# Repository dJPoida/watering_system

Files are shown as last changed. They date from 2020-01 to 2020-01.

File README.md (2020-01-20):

# dJPoidas Watering System
dJPoida's automated garden watering system.

This is a simple project for activating a water pump that sits inside a small reservoir to regularly water my herbs because I'm a numpty and always seem to forget. Homemade pizza is much nicer with fresh Basil, Oregano and Chilli!

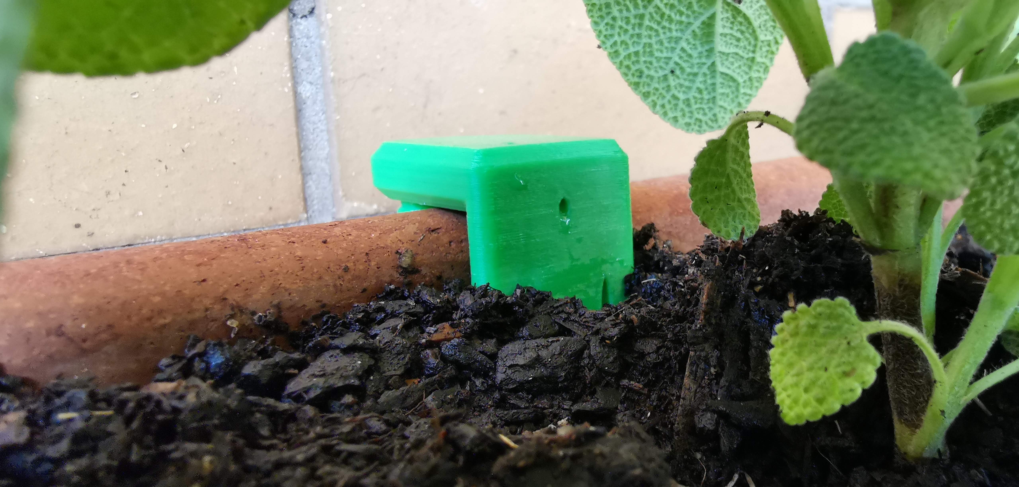
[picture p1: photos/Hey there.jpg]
Hey there

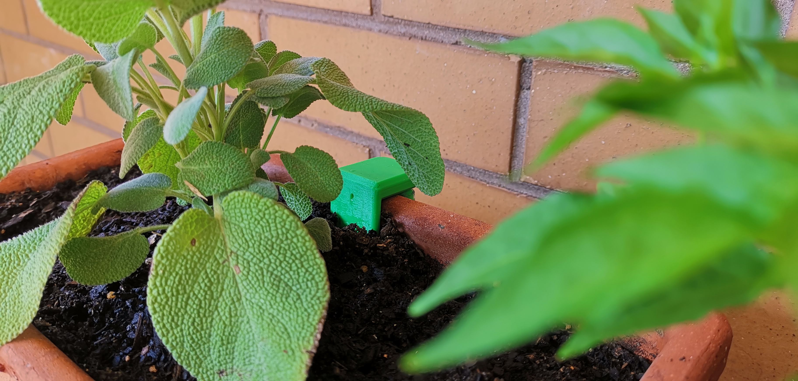
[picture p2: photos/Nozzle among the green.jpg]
Nozzle among the green

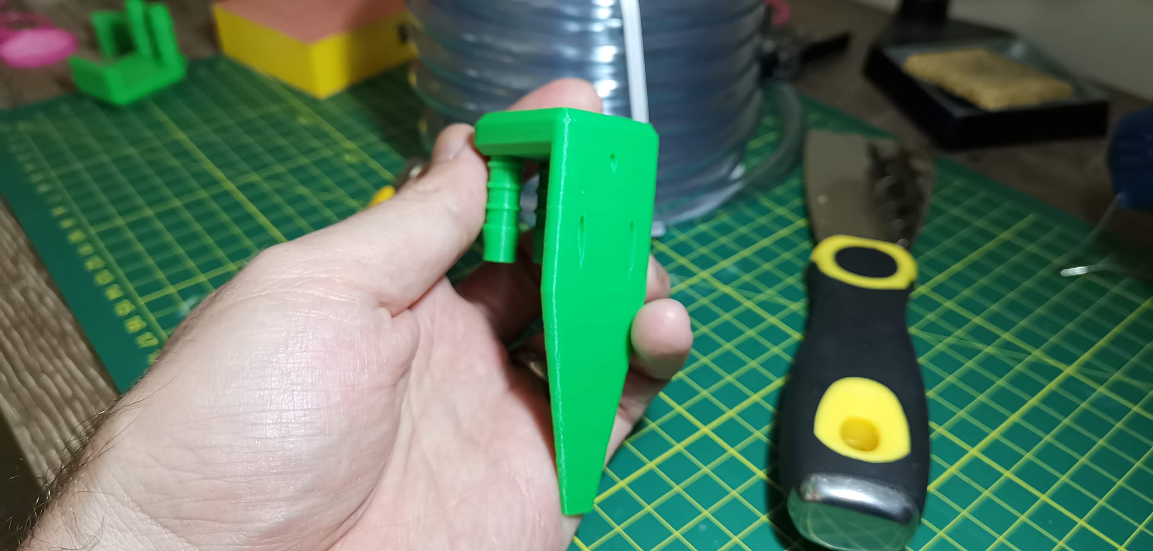
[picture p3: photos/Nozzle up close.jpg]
Nozzle up close

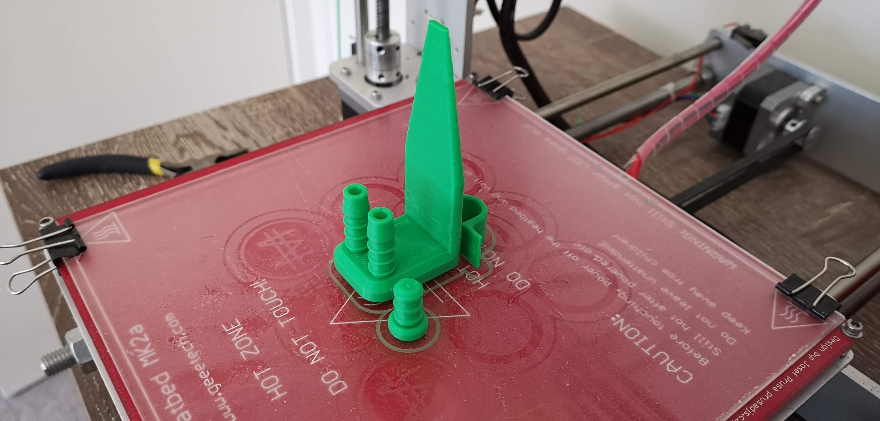
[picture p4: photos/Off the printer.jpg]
Off the printer

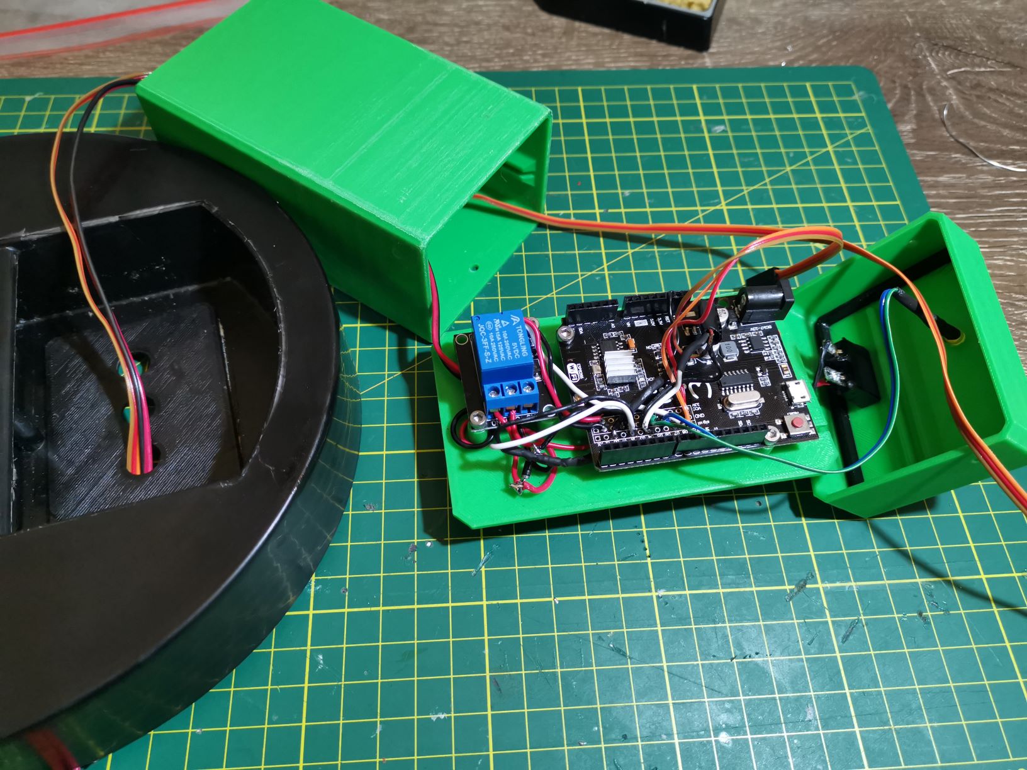
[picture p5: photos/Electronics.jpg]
Electronics

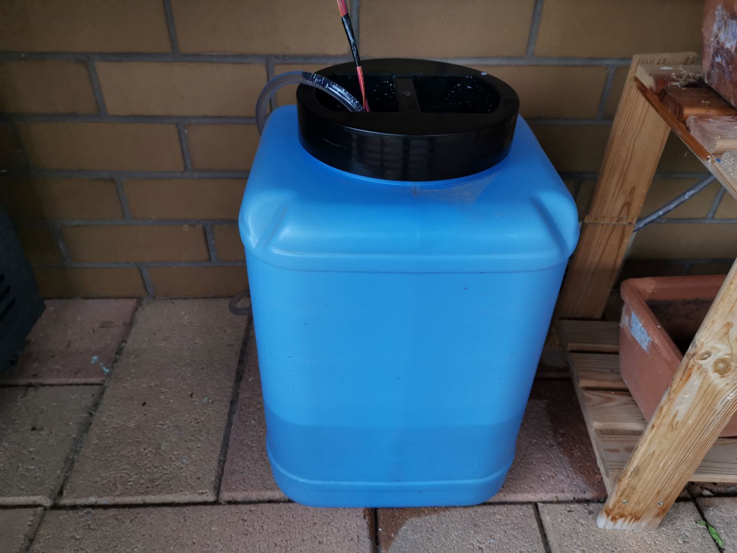
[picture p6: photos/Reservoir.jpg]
Reservoir

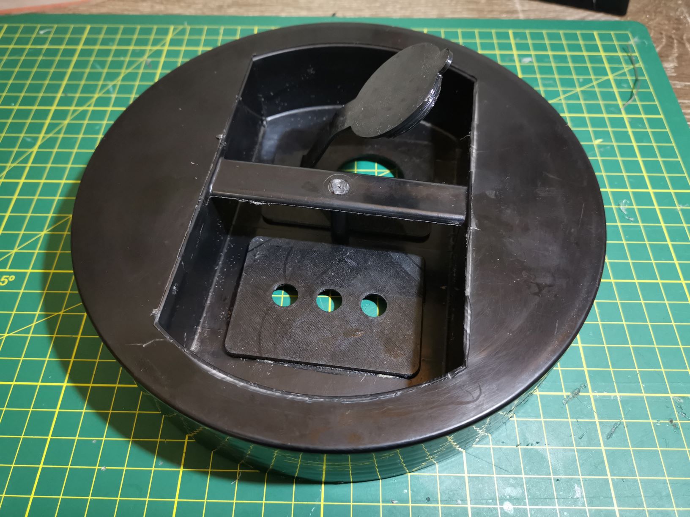
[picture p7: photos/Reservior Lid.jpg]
Reservior Lid


## Dependencies
### Arduino
The code for this project is written for the Arduino platform.
### Blynk
This project leverages the [Blynk IoT platform](https://blynk.io/) for remote management and reporting.

## Instructions
- Clone the repo
- Copy the `config_example.h` to `config.h` and populate with your appropriate config values. Specifically:
    - `blynkAuthToken[]`
    - `ssid[]`
    - `pass[]`
- Set your board config properly before uploading or the pins and flash won't work properly: 
    - LOLIN(WEMOS) D1 R2 & Mini
    - Flash Size: 4M (1M SPIFFS)
- Install Blynk on your control device (mobile / tablet) and load the control app by scanning the QR Code

## Blynk App
This is what the Blynk control app looks like
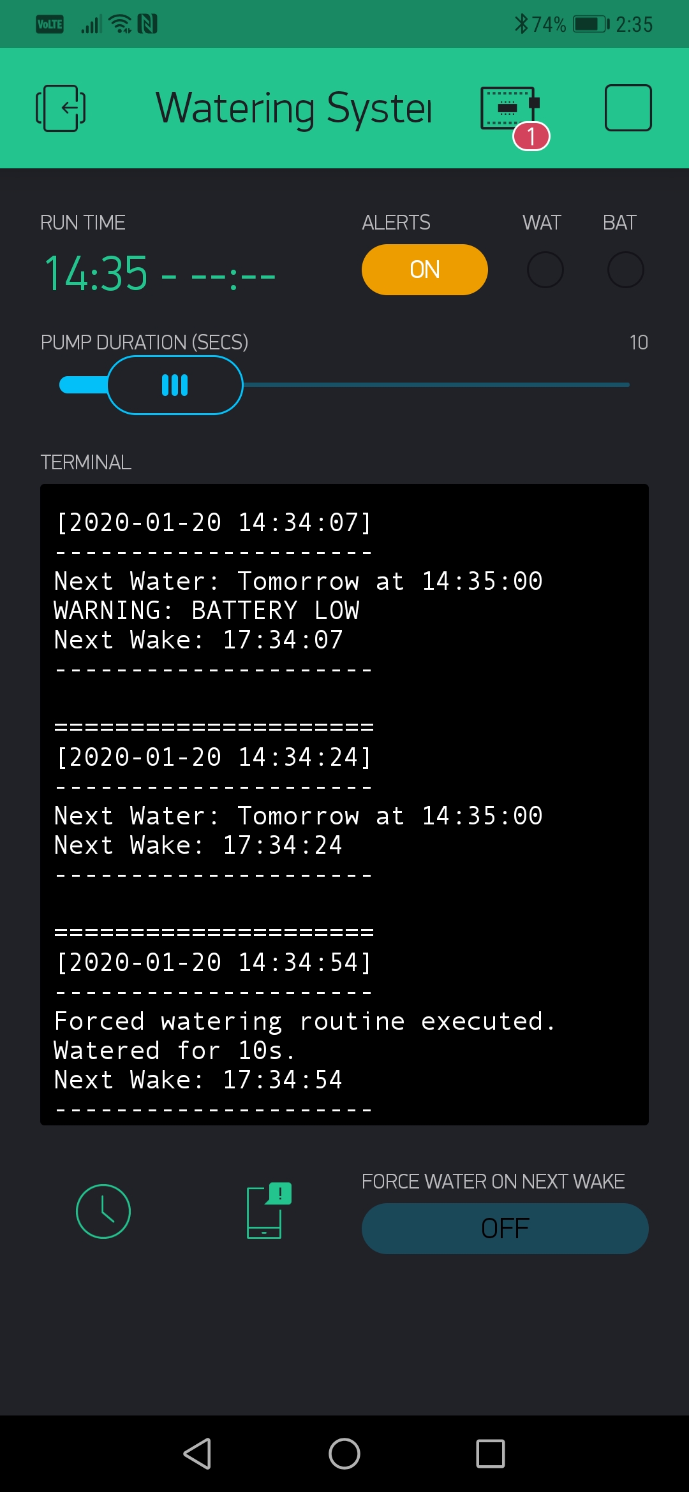
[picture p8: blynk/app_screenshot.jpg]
Blynk Screenshot


To start with the Blynk app I created, scan this code in blynk
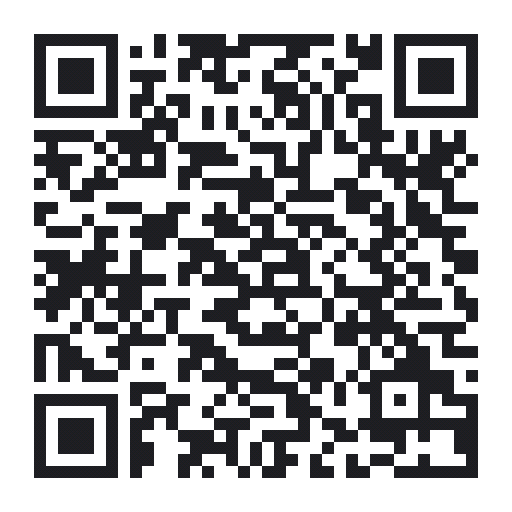
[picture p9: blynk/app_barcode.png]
Blynk App


## Schematic
**Note:** the Wemos D1 R2 Fritzing part isn't perfect so this schematic is mostly representative.
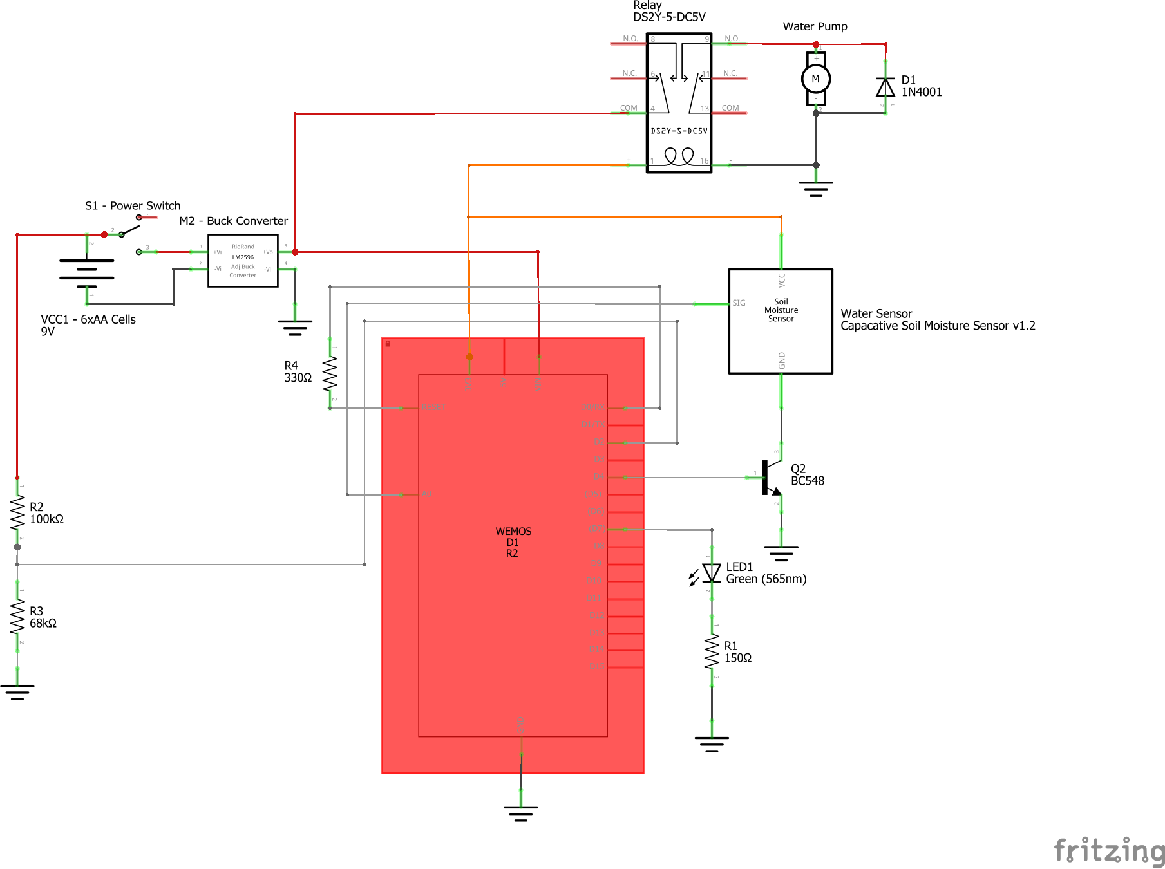
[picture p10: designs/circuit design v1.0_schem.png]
Schematic


## Breadboard
**Note:** the Wemos D1 R2 Fritzing part isn't perfect so this breadboard diagram is mostly representative.
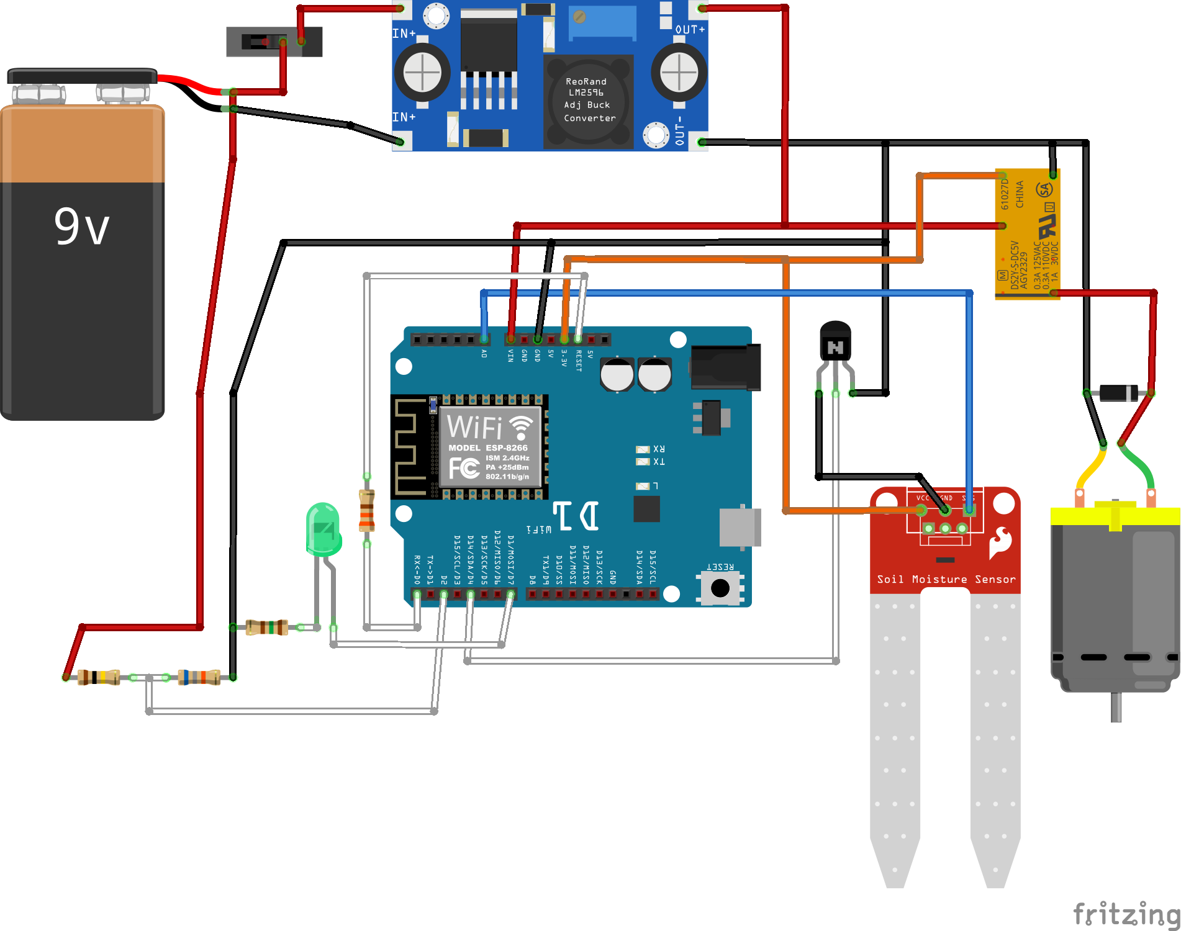
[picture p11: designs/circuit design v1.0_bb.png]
Breadboard


## Workflow
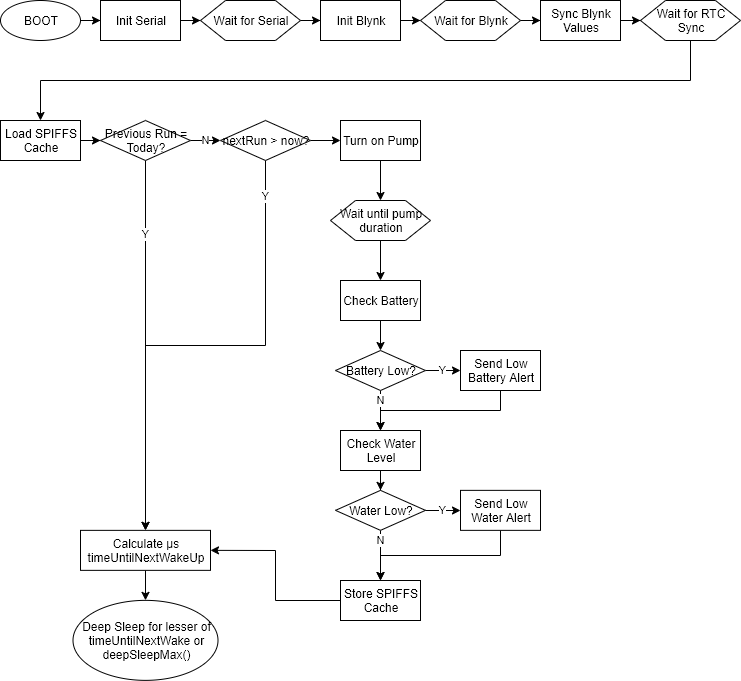
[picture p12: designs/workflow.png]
Workflow


## SPIFFS Cache file
The data stored in SPIFFS is nothing complex and simply assists in the determination of next watering time.

- Line 1: Date last executed watering routine (stored as a `long` formatted `YYYYMMDD`)
- Line 2: Time of day last executed watering routine (stored as a `long` in 24hr format `HHMMSS`)
```
20200119
160212
```
The above data indicates that the watering routine was last executed at 4:02:12pm on January 19, 2020.

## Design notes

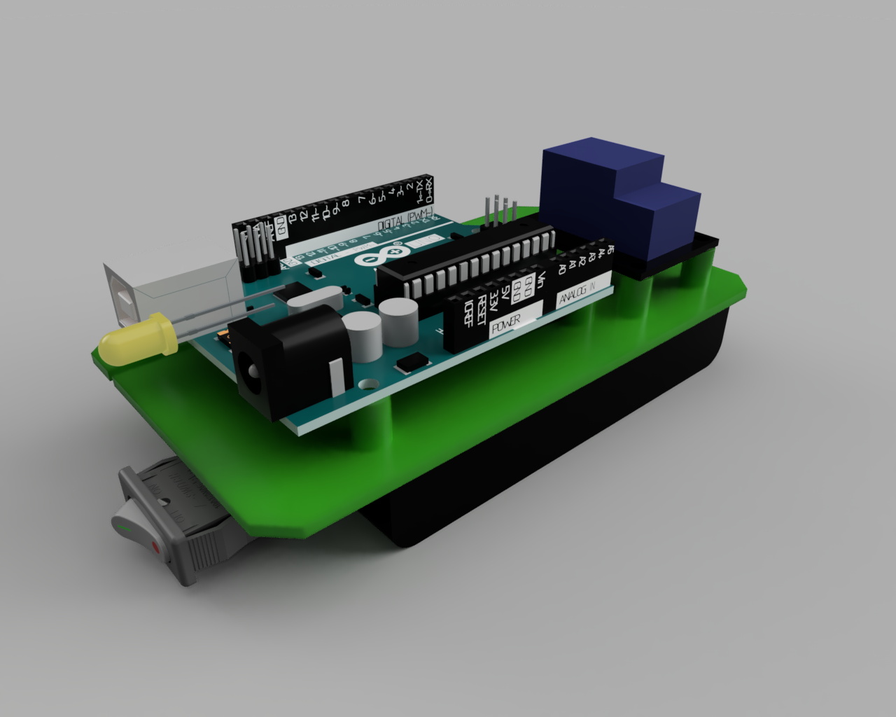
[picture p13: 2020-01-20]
cad/Electronics Housing/Electronics.png

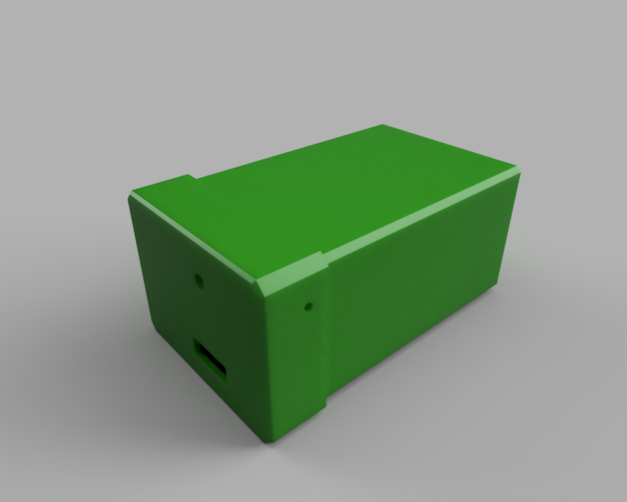
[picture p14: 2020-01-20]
cad/Electronics Housing/Electronics Housing.png

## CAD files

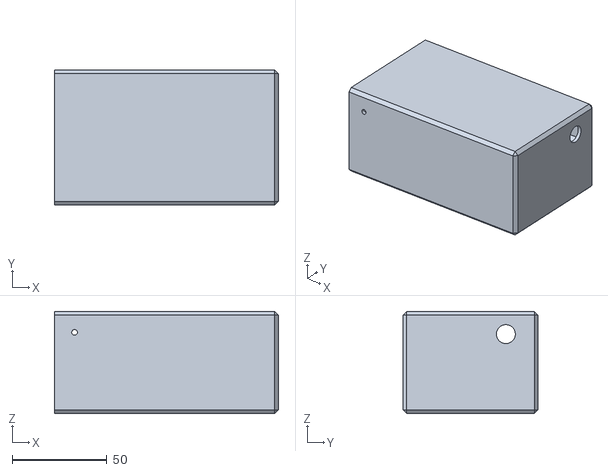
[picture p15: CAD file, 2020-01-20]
cad/Electronics Housing/Shell.stl
118.4 x 71.4 x 54.0

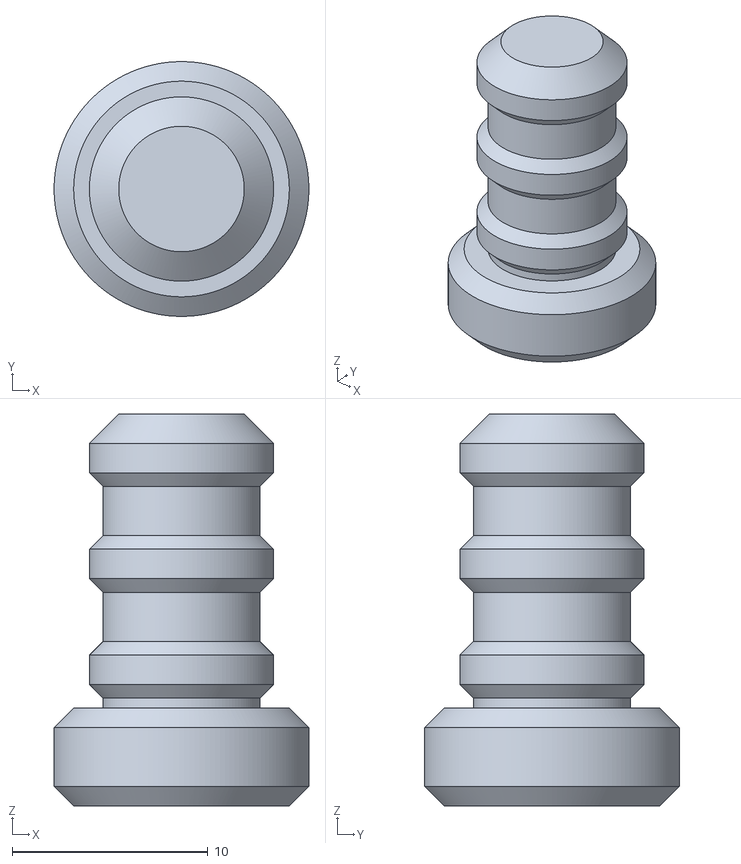
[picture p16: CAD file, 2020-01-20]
cad/Hose Clips and Nozzles/Hose Plug.stl
13.0 x 13.0 x 20.0

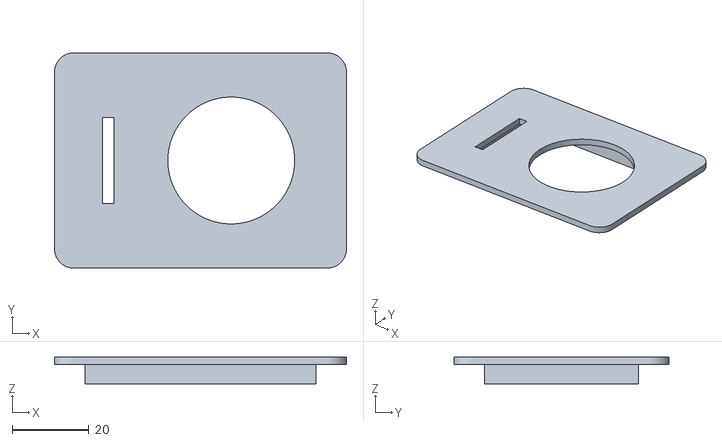
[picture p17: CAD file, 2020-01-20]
cad/Reservoir/Reservoir Refill Port.stl
76.0 x 56.0 x 7.00

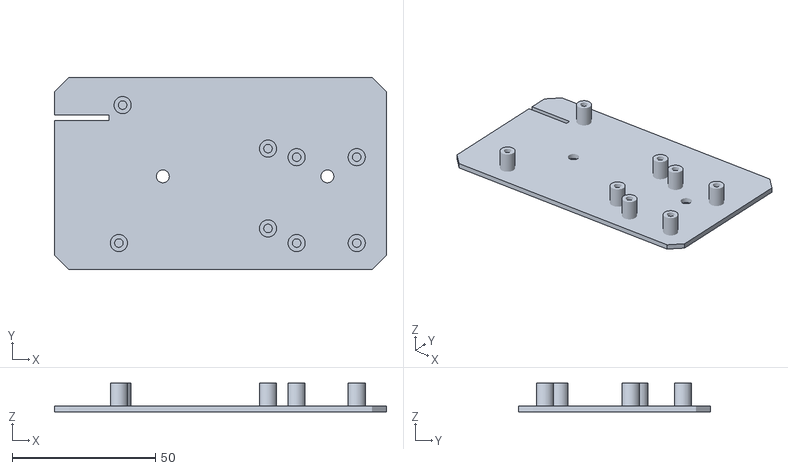
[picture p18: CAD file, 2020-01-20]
cad/Electronics Housing/Base.stl
116.0 x 67.0 x 10.0

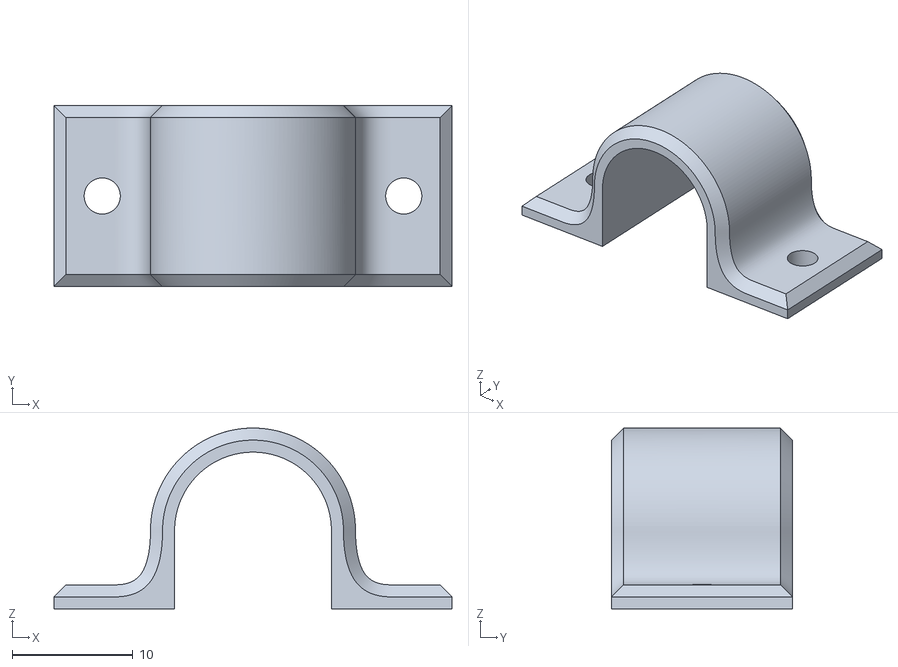
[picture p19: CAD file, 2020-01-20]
cad/Hose Clips and Nozzles/Hose Clip.stl
33.0 x 15.0 x 15.0

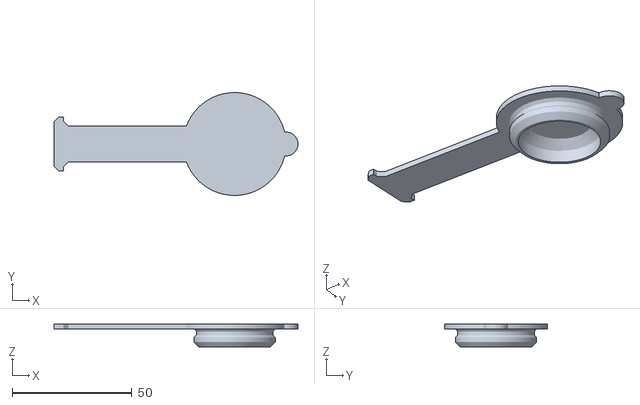
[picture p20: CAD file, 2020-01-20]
cad/Reservoir/Reservoir Refill Cap.stl
102.0 x 43.0 x 9.50

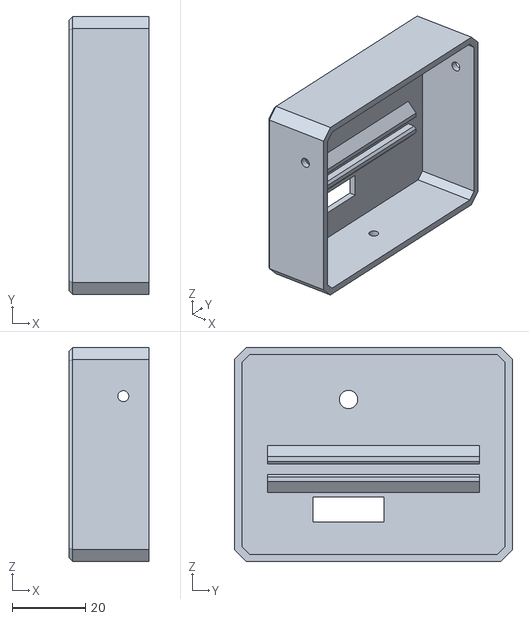
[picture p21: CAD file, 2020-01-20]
cad/Electronics Housing/Lid.stl
21.8 x 75.8 x 58.4

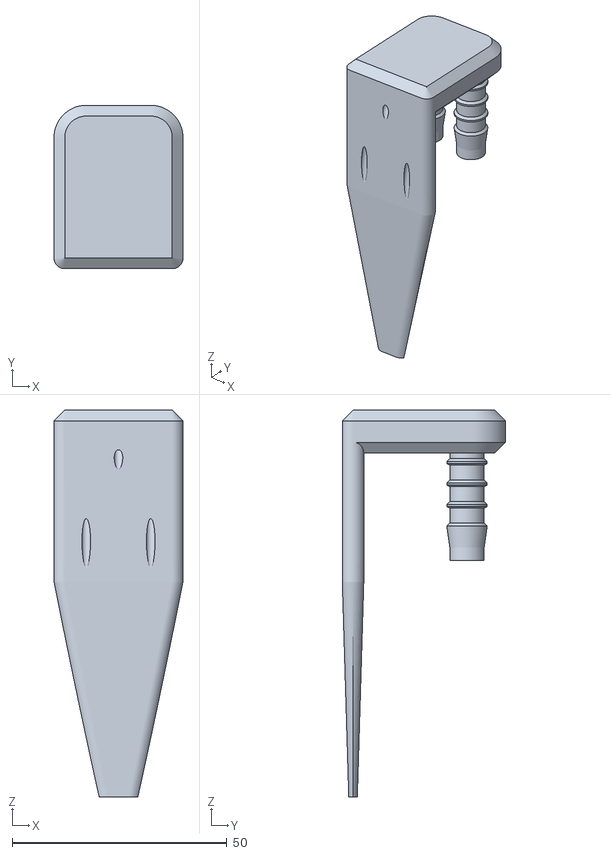
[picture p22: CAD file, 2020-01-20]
cad/Hose Clips and Nozzles/Pot Nozzle.stl
30.0 x 38.0 x 90.0

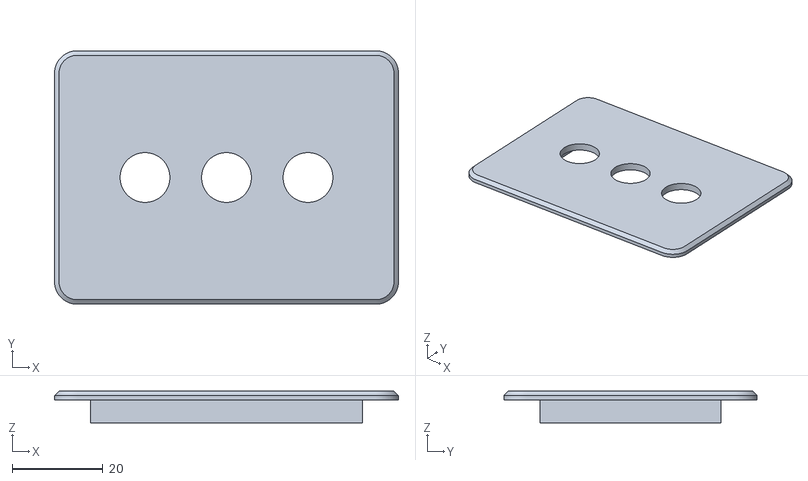
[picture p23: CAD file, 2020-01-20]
cad/Reservoir/Reservoir Hose Ports.stl
76.0 x 56.0 x 7.00

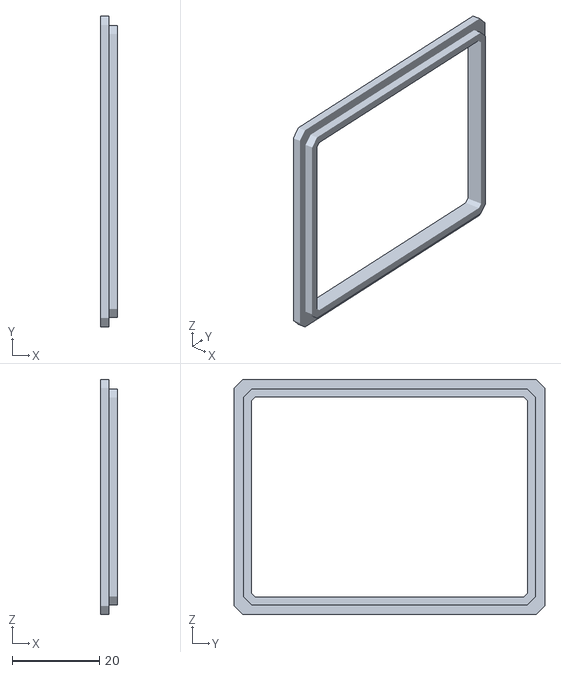
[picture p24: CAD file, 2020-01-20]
cad/Electronics Housing/Seal.stl
4.00 x 71.4 x 54.0

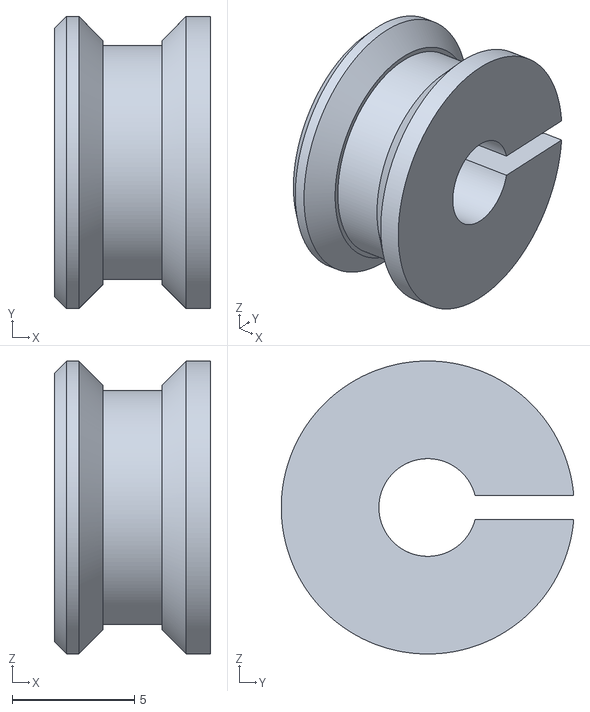
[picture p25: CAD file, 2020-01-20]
cad/Electronics Housing/WirePlug.stl
6.40 x 12.0 x 12.0

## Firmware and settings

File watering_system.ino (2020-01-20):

/**
 * dJPoida's Watering System
 * Peter Eldred 2020-01
 * License: MIT
 * 
 * Board: Wemos D1 R2
 * Peripherals:
 *  - Capacitive Soil Moisture Sensor for detecting water tank water out level
 *  - Brushless 12v DC Submersable Pump AD20P-1230C
 *  - LED for physical running indication
 *  - DC Relay
 *  - 9v Power Supply (6x AA Cells)
 *  - Step-up Buck Converter tuned to 12v
 */
#include "config.h"
#include <ESP8266WiFi.h>
#include <BlynkSimpleEsp8266.h>
#include <TimeLib.h>
#include <FS.h>
#include <WidgetRTC.h>


// Globals

// Blynk Terminal Widget
WidgetTerminal terminal(PIN_BLYNK_TERMINAL);

// Blynk RTC Widget
WidgetRTC rtc;

// Blynk Low Water LED
WidgetLED blynkLED_lowWater(PIN_BLYNK_LOW_WATER_LED);

// Blynk Low Battery LED
WidgetLED blynkLED_lowBattery(PIN_BLYNK_LOW_BATTERY_LED);

// Boolean for water level OK
bool waterOk = true;

// Boolean for battery level OK
bool batteryOk = true;

// Boolean to determine if we're connected to Blynk
bool connectedToBlynk = false;

// Boolean to control whether the app wants push notifications or not
bool sendAlertsEnabled = false;

// Boolean to override whether the watering routine should be run or not
bool forceWaterRoutine = false;

// Boolean to flag whether or not the watering routine was executed
bool wateringExecuted = false;

// The duration the pump should run for (in seconds)
int pumpDuration = 5000;

// The time of day the watering activity is supposed to take place (HHMMSS)
long dailyWateringTime = 0;

// The time of day the watering activity is supposed to take place in seconds()
long dailyWateringTimeInSeconds = 0;

// the number of seconds until the next watering routine should be executed
long timeUntilNextWaterInSeconds = 0;

// The date the watering activity was last run (YYYYMMDD)
long lastExecutedDate = 0;

// The time of day the watering activity was last run (HHMMSS)
long lastExecutedTime = 0;

// The time the device should sleep for (in microseconds)
uint64_t sleepDuration = SLEEP_DEFAULT;

// The time the device should sleep for (in seconds)
long sleepDurationInSeconds = SLEEP_DEFAULT / 1000000;


/**
 * The main routine runs in setup.
 */
void setup() {
  Serial.begin(9600);
  Serial.println("Awake.");

  // Setup the peripherals
  SPIFFS.begin();
  setupLED();
  setupPump();
  setupWaterSensor();

  // Connect ot the Blynk service()
  connectedToBlynk = connectToBlynk();

  // restore the cache
  restoreCache();

  // check the battery
  checkBattery();

  // check the water
  checkWater();

  // send any alerts
  sendAlerts();

  // calculate the time until the next watering event
  calculateTimeUntilNextWater();

  // Run the watering routine (if required)
  if ((!wateringAlreadyRunToday() && (timeUntilNextWaterInSeconds < 0)) || forceWaterRoutine) {
    executeWateringRoutine();
  }
  
  // store the cache
  storeCache();

  // Calculate how long the device should sleep for
  calculateNextSleepDuration();

  // Send the report to Blynk
  sendReport();

  // sleep
  sleep();
}

void loop() {
  // de nada. Everything happens in setup.
}

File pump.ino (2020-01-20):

#include "config.h"

/**
 * Setup the pump
 */
void setupPump() {
  pinMode(PIN_PUMP, OUTPUT);
  digitalWrite(PIN_PUMP, LOW);
}


/**
 * Actiates the water pump
 */
void pumpOn() {
  Serial.println("Pump: On");
  digitalWrite(PIN_PUMP, HIGH);
}


/**
 * Deactivates the water pump
 */
void pumpOff() {
  Serial.println("Pump: Off");
  digitalWrite(PIN_PUMP, LOW);
}


/**
 * Execute the watering routine
 */
void executeWateringRoutine() {
  lastExecutedDate = currentRTCDate();
  lastExecutedTime = currentRTCTime();
  wateringExecuted = true;
  
  Serial.println("########");
  Serial.println("WATERING... ");
  Serial.println("########");

  ledOn();
  pumpOn();
  long timeStarted = millis();
  while ((millis() - timeStarted) < pumpDuration) {
    delay(50);
  }
  pumpOff();
  ledOff();
}

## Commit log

2020-01-19 Circuit Designs
    [circuit design v1.0.fzz]
2020-01-19 Updated schematic
    [circuit design v1.0.fzz]
2020-01-20 Added cad and blynk app assets
    [Base.stl, Hose Clip.stl, Hose Plug.stl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]
